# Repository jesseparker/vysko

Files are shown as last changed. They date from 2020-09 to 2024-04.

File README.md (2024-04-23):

# vysko
Promising results... (https://www.youtube.com/watch?v=EKHszj4jTb0) It's a video!  Click it!

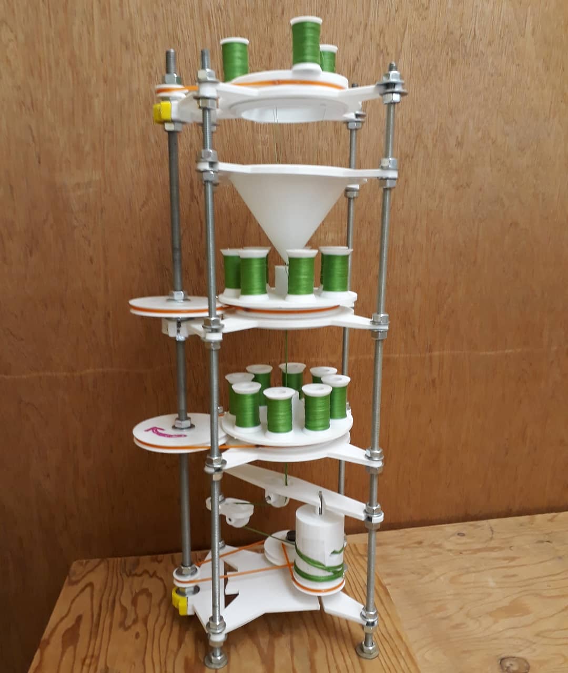
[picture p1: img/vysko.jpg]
Vysko Version 1


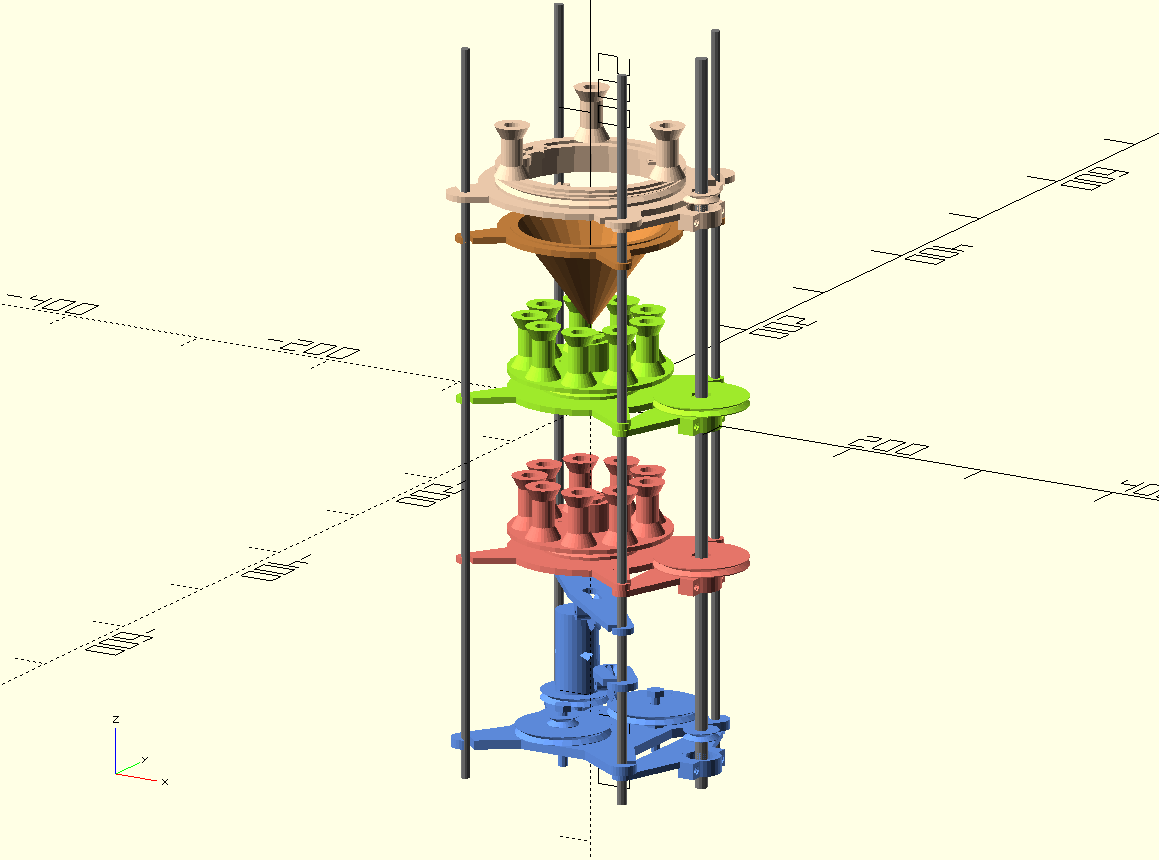
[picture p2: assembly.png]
OpenSCAD Model


Open Source Fuse Machines

2 machines are included here:

- A "visco" style fuse making machine
- A blackmatch making machine

VYSKO

Most of the files here are parts for a fuse weaving machine for making fuse with a powder core, wrapped in 2 layers of helical-wound thread.

If you search online you will find several handmade machines for making this kind of fuse.  They are typically 100% custom machines, and they are typically pretty big or even commercial-size.

This machine is designed for hobbyist use.  It is limited in the length of completed fuse that can be produced - there's only so much room for thread and finished fuse.  This machine is comparatively compact, is very adjustable, and can be made without specialized components.

In addition to several copies of several printed parts you will need:

- 4 1/4" threaded rod 24" long
- 1 5/16" threaded rod 24" long
- 2 2mm shaft 10 cm long
- 3 608 bearings ("skateboard bearings")
- 2 mm round polyurethane belt ~ 2 meters
- 2 1/4" 1 1/2" bolt
- 1 8" x 8" x 3/4" plywood baseplate
- 1000 yards cotton sewing thread
- Meal (pyrotechnic composition)
- ~ 130 1/4" nuts
- ~ 200 #12 flat washers
- ~ 20 5/16" nuts
- ~ 20 1/4" flat washers

Not much documentation available at this time!  Good luck!

Blackmatch Machine

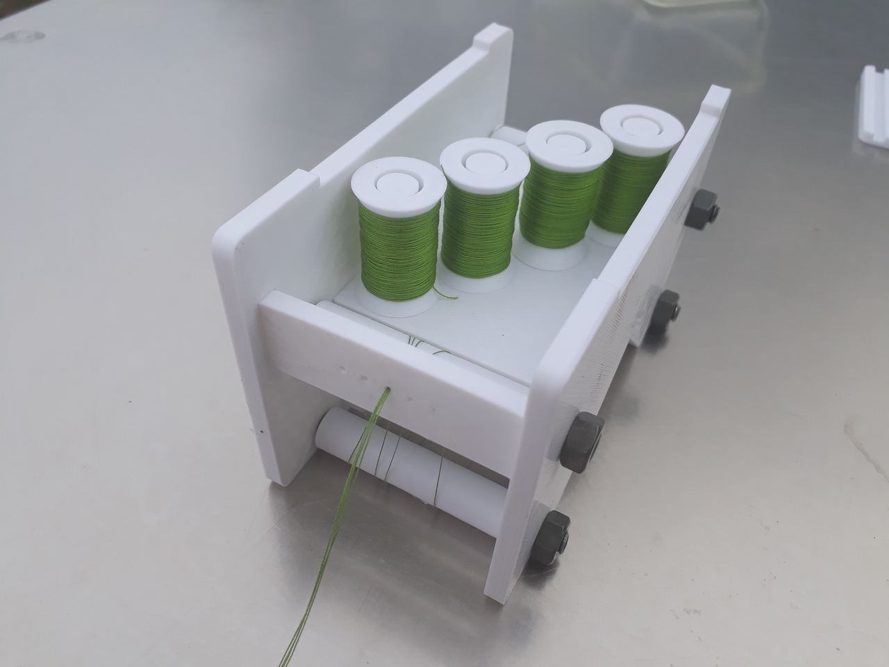
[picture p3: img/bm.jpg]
Blackmatch Version 1


This machine is for making blackmatch which is a basic fuse used in pyrotechnics.  Blackmatch can be used as a fuse, and is also used to make quickmatch.

In addition to about 12 printed parts you will need:

- 4 1/4" 3" bolts + nuts
- Cotton crochet thread #10 size (or similar)
- Meal + 5% dextrin (pyrotechnic composition)

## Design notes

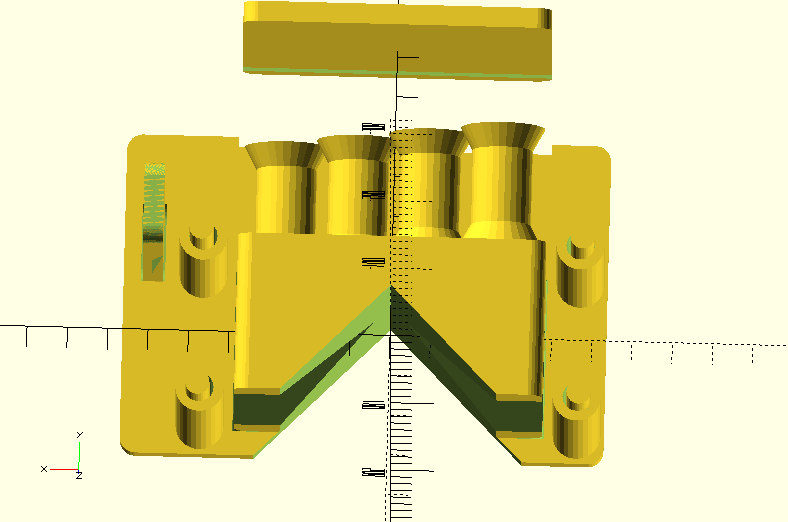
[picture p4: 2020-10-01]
img/bmatch6.png

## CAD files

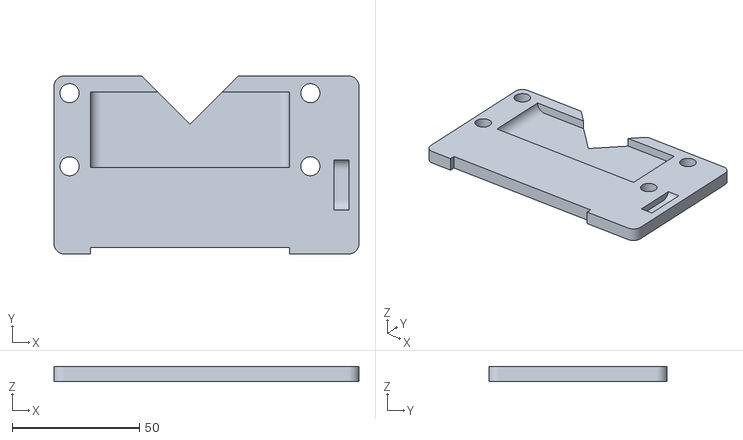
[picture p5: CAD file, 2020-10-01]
stl/blackmatch/side_b.stl
120.0 x 70.0 x 6.00

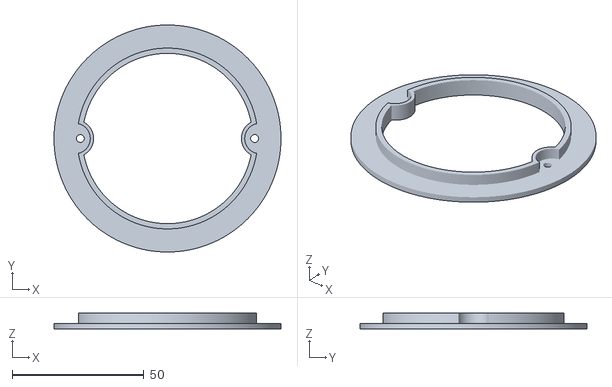
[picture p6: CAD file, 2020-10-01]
stl/vysko/spinner_key_x3.stl
86.0 x 86.0 x 6.00

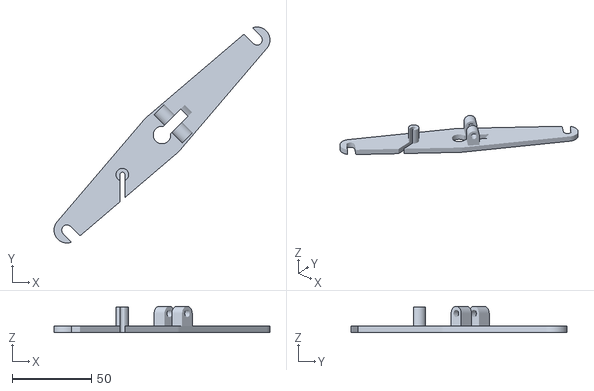
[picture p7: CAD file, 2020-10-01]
stl/vysko/strut_center_pulley.stl
136.2 x 136.2 x 16.6

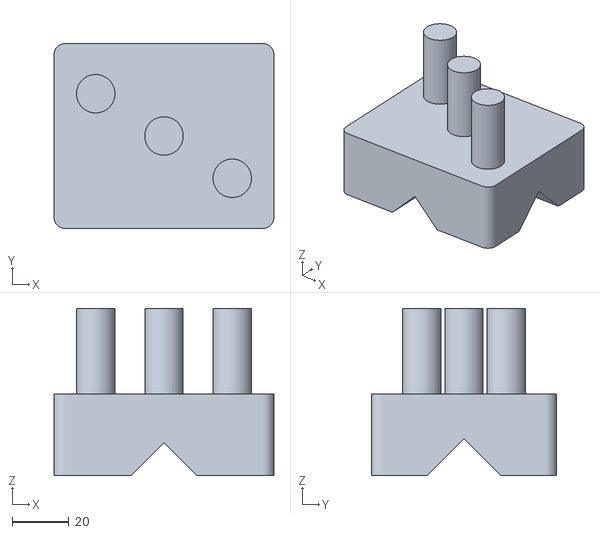
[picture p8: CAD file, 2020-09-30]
stl/blackmatch/body.stl
77.2 x 65.0 x 58.8

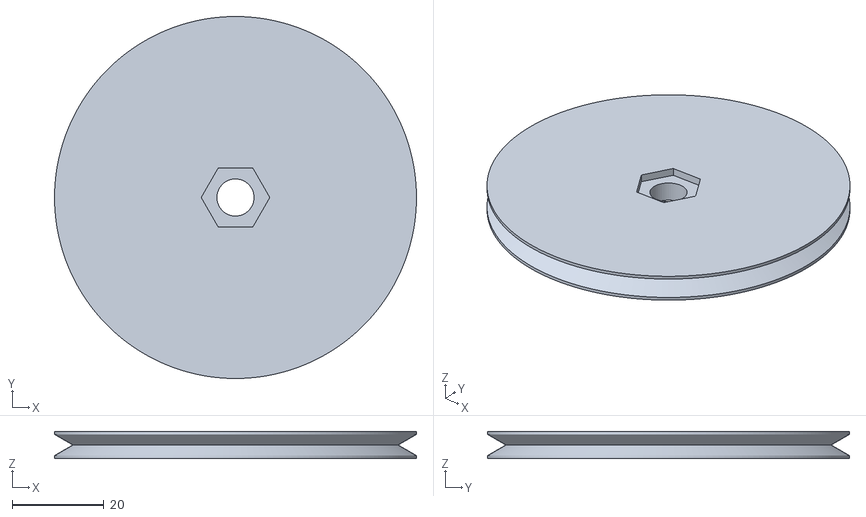
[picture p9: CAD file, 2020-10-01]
stl/vysko/driveshaft_pulley_75mm.stl
79.0 x 79.0 x 6.00

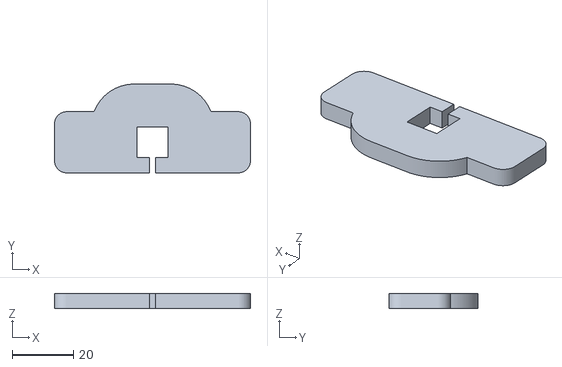
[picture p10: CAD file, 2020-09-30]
stl/blackmatch/die_holder.stl
64.0 x 29.0 x 5.00

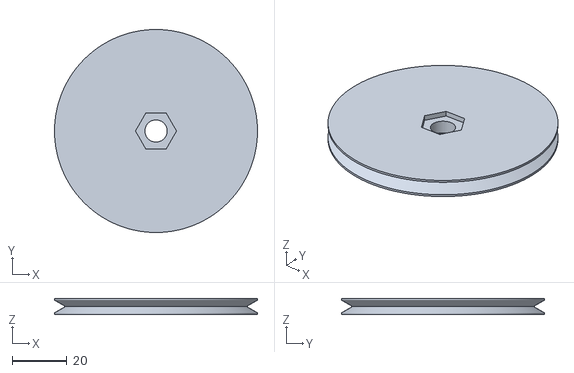
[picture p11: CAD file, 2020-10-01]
stl/vysko/driveshaft_pulley_70mm.stl
74.0 x 74.0 x 6.00

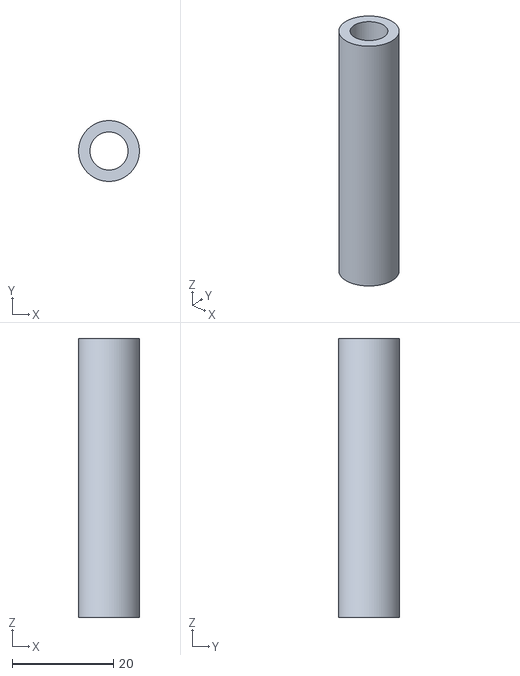
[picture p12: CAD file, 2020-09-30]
stl/blackmatch/roller_x4.stl
12.0 x 12.0 x 55.0

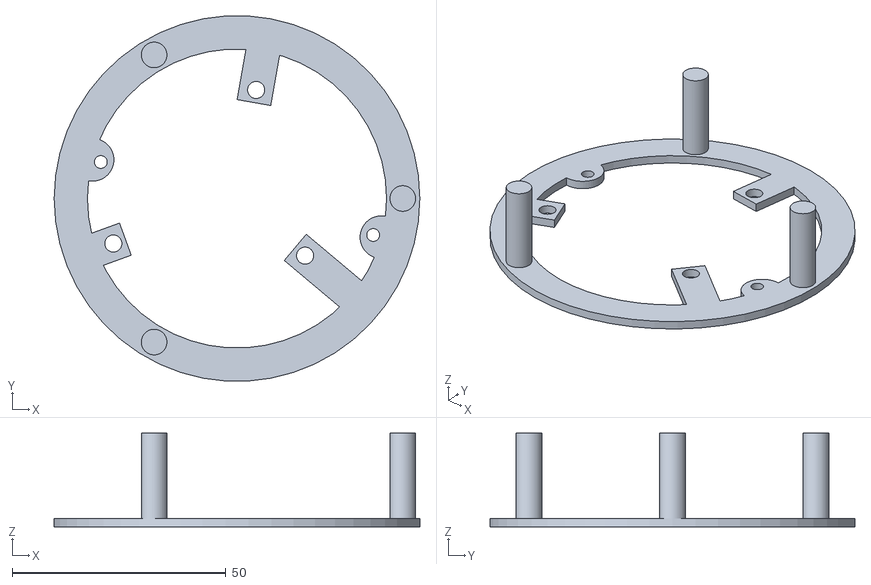
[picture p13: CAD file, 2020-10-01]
stl/vysko/tracer_plate.stl
85.6 x 85.4 x 22.0

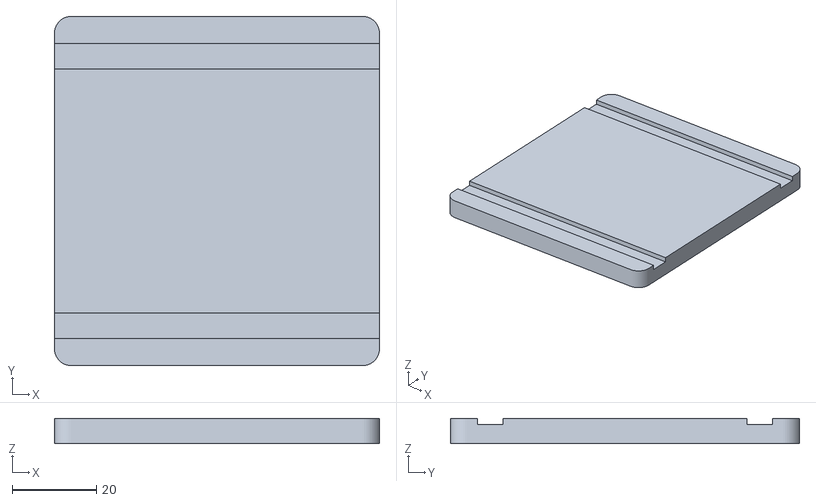
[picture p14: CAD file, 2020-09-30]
stl/blackmatch/retainer.stl
77.2 x 83.0 x 6.00

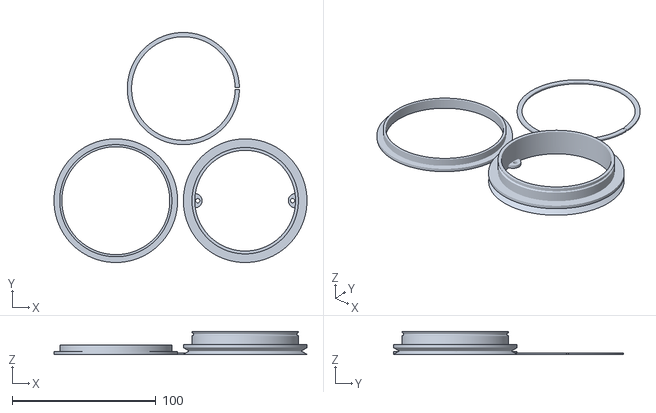
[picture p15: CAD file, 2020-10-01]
stl/vysko/spinner_bearing_x3.stl
176.0 x 160.0 x 16.1

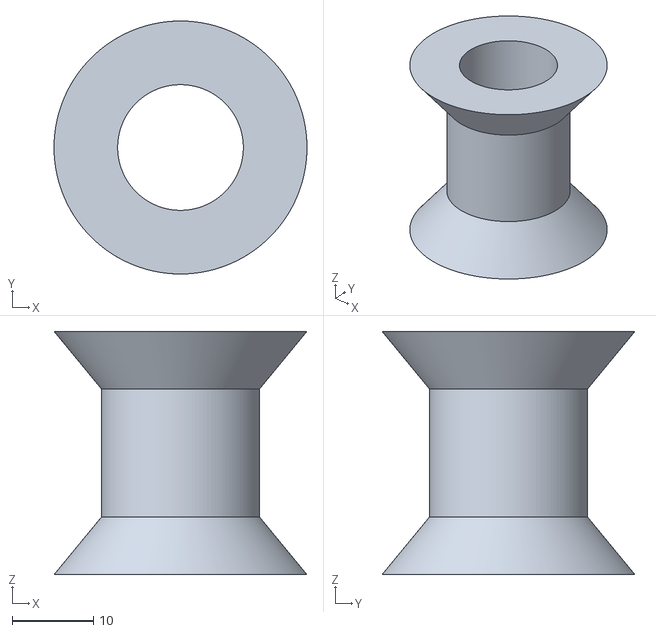
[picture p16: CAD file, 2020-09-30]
stl/blackmatch/spool_x3.stl
31.2 x 31.2 x 30.0

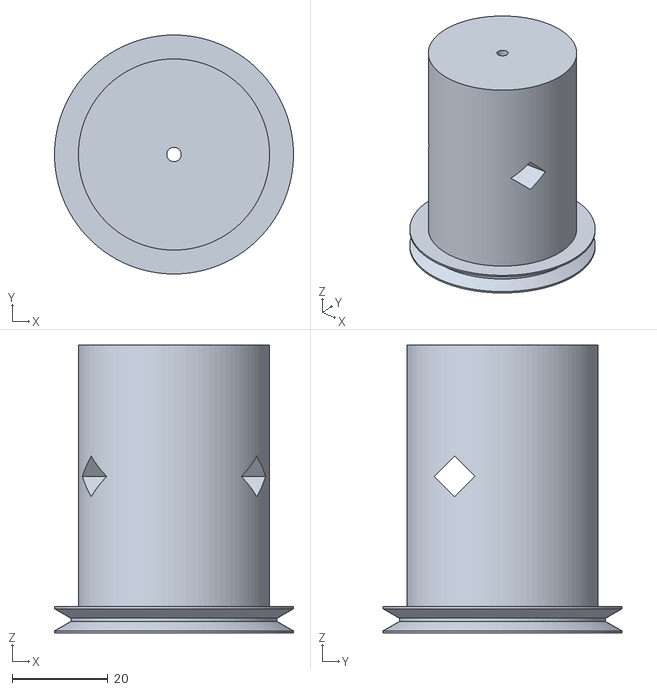
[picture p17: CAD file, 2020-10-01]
stl/vysko/drum.stl
50.0 x 50.0 x 60.2

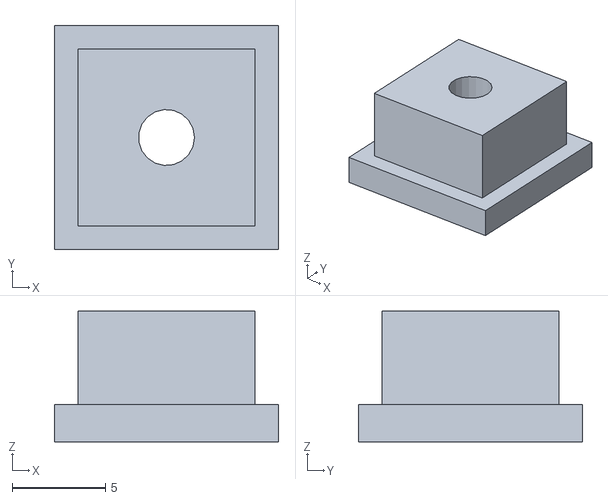
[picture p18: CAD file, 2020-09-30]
stl/blackmatch/die_3mm.stl
12.0 x 12.0 x 7.00

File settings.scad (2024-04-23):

//
//$fn = 100;
//$fn = 30;
smidge=.01;

lhf = .35;  // Layer Height FFFFirst
lh = .3; // Layer Height

// in this model there are "z axis" tolerances that are 
// in the range of a 3d printer layer height.  Some dimensions 
// need to be modelled as actual printed heights.  Adjust lhf and lh
// (above) for your slicer settings.
// layer_multiple() returns the closest layer height >= a distance
function layer_multiple(z) = (z <= lhf) ? lhf : lhf+lh*(ceil((z-lhf)/lh));
//foo = layer_multiple(100);
//echo(foo);

frame_x = 120;
frame_y = frame_x;
frame_rod_diameter=8;

frame_rod_r = 6.5/2;
frame_length = 500;


drive_axle_r = 8.1/2;
drive_axle_bearing_id = 8;
drive_axle_bearing_od = 22.5;
drive_axle_bearing_t = 8;

bearing_holder_wall = 1.2;
bearing_holder_tie_hole_r = 3/2;
bearing_holder_cut = -1;

bearing_pillow_rim_t = 2;
bearing_pillow_side_t = 1.5;
bearing_pillow_screw_thread_r = 3/2;
bearing_pillow_screw_shank_r = 4/2;
bearing_pillow_screw_head_r = 6/2;

drive_position_x = frame_x/2+ 25;
drive_position_y = 0;

strut_t = layer_multiple(4);

//spool
spool_d = 15;
spool_h = 35;
spool_flange_ratio=.8;
spool_hole = spool_d - 4; // hole diameter
spool_slope=1/6; // angle of conical section
spool_shaft_tol=2;

// rollers for winder 
center_pulley_r = 10;
center_pulley_t = 5;
center_pulley_angle = 45;
center_pulley_axle_r = 1.5;
center_pulley_axle_l = 30;

spinner_center_hole_r = 25;
tracer_center_hole_r = 55;

funnel_h = 70;
funnel_r = 50;
funnel_wall = 2.5;
funnel_flange = 3;
funnel_flange_t = 1;

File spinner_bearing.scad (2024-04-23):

include <settings.scad>
include <hollow_bearing.scad>
use <v_pulleys.scad>

$fa=1; $fs=.5;

inner_hole_r = spinner_center_hole_r;
shell_wall = 2;
inner_shell_wall = shell_wall;
outer_shell_wall = shell_wall/2;
shell_t = 2; 
flange_w = shell_t*2;
inner_outer_tolerance = 1;
journal_t = strut_t;
journal_tolerance = 1;
journal_tolerance_z = lh;

retainer_t = layer_multiple(1);
retainer_d = inner_shell_wall /2;
retainer_w = retainer_d*2+inner_outer_tolerance;
retainer_tolerance=.1;

spinner_pulley_t = 5;
spinner_single_pulley_t = 6;
spinner_pulley_attach = .1;

spinner_pulley_center_z = shell_t+journal_t/2+journal_tolerance_z/2+spinner_pulley_t/2-spinner_pulley_attach;
//spinner_pulley_center_z =0;
//spinner_pulley_center_z =0;
/*
shell_r = inner_hole_r + inner_shell_wall + outer_shell_wall + inner_outer_tolerance + flange_w ;
inner_shell_h = journal_t + shell_t*2 + retainer_t*2 + journal_tolerance_z+retainer_tolerance*2;
outer_shell_h = journal_t + shell_t +journal_tolerance_z;

*/

spinner_key_t = 2;
spinner_key_insert = 4;

module spinner_connect_holes() {
         translate([-inner_hole_r+2,0,-spinner_pulley_t+spinner_pulley_attach])
            cylinder(r=1.5,h=20,center=true);
         translate([inner_hole_r-2,0,-spinner_pulley_t+spinner_pulley_attach])
            cylinder(r=1.5,h=20,center=true);
}

module spinner_connect_tabs() {
    difference() {
        union() {
            translate([inner_hole_r,0,-spinner_pulley_t+spinner_pulley_attach])
                cylinder(r=5,h=2);
            translate([-inner_hole_r,0,-spinner_pulley_t+spinner_pulley_attach])
                cylinder(r=5,h=2);
        }
        spinner_connect_holes();
    }    
}
//spinner_connect_tabs();
module spinner_key(t=spinner_key_t, tol=0) {
    difference() {
        union() {
    difference() {
        union() {
        translate([0,0,-t/2])
            cylinder(r=shell_r, h=t, center=true);
            
        translate([0,0,spinner_key_insert/2])
            cylinder(r=inner_hole_r-tol/2, h=spinner_key_insert, center=true);
            
        translate([0,0,spinner_key_insert/2-smidge])
            cylinder(r=inner_hole_r-tol/2, h=spinner_key_insert, center=true);


            
        }
cylinder(r=inner_hole_r-tol/2-t, h=20, center=true);    
    }
    intersection() {
            translate([inner_hole_r,0,+(spinner_key_insert-t)/2])
                cylinder(r=5+t,h=t+spinner_key_insert, center=true);
            cylinder(r=inner_hole_r-tol/2, h=spinner_key_insert*2, center=true);
    }
    intersection() {
            translate([-inner_hole_r,0,+(spinner_key_insert-t)/2])
                cylinder(r=5+t,h=t+spinner_key_insert, center=true);
            cylinder(r=inner_hole_r-tol/2, h=spinner_key_insert*2, center=true);
    }
}
    translate([inner_hole_r,0,+(spinner_key_insert-t)/2+t])
        cylinder(r=5+tol/2,h=t+spinner_key_insert, center=true);
    translate([-inner_hole_r,0,+(spinner_key_insert-t)/2+t])
        cylinder(r=5+tol/2,h=t+spinner_key_insert, center=true);
         spinner_connect_holes();   
    }
}
//translate([0,0,-shell_t-journal_t/2-journal_tolerance_z/2-spinner_pulley_t/2-spinner_pulley_t+spinner_pulley_attach])
//!spinner_key();

module spinner_inner_shell() {

    inner_shell();
    translate([0,0,-spinner_pulley_t/2+spinner_pulley_attach])
    belt_pulley(
        d = shell_r*2-4,
        shaft_d=inner_hole_r*2,
        belt_d=2,
        t= spinner_pulley_t,
        wedge_factor=.4
    );
    spinner_connect_tabs();
}

//spinner_inner_shell();

module spinner_outer_shell() {
    outer_shell();
}

module spinner_journal() {
    journal();

}

module spinner_retainer_ring() {
    retainer_ring();
}

//module spinner_center_hole() {
//    center_hole();
//}

module spinner_bearing_assembly() {
//intersection() {
translate([0,0,shell_t+journal_t/2+journal_tolerance_z/2])
spinner_outer_shell();

    translate([0,0,-shell_t-journal_t/2-journal_tolerance_z/2]) {
    spinner_inner_shell();

   translate_retainer()
  spinner_retainer_ring();
}

translate([0,0,-shell_t-journal_t/2-journal_tolerance_z/2-spinner_pulley_t+spinner_pulley_attach-1])
spinner_key(tol=1.5);
    

spinner_journal();
//}

}
//spinner_center_hole();
spinner_bearing_assembly();

module spinner_bearing_print_all() {
translate([0,0,0])
rotate(180, [0,1,0])
spinner_outer_shell();
translate([shell_r*2+4,0,spinner_pulley_t-spinner_pulley_attach]) 
    spinner_inner_shell();
    
//translate([0,shell_r*2+flange_w*2,journal_t/2])
//spinner_journal();
//translate([shell_r+flange_w*3+inner_hole_r,shell_r+flange_w*2+inner_hole_r,retainer_t/2])
translate([shell_r+flange_w,shell_r+inner_hole_r,retainer_t/2])
spinner_retainer_ring();
    
}


//spinner_bearing_print_all();

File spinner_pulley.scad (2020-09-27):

include <jplib.scad>
include <settings.scad>
include <spinner_bearing.scad>
//include <bearing.scad>
include <nuts_washers.scad>
include <v_pulleys.scad>
//include <rods.scad>

//$fn = 30;

module spinner_single_pulley(d=20) {
    difference() {
        union() {
            belt_pulley(
                d = d,
                shaft_d=drive_axle_r*2,
                belt_width=3,
                slope=.5,
                t= spinner_single_pulley_t
            );
        }
        translate([0,0,-spinner_pulley_center_z])
            bearing_translate()
                drive_bearing_top_washer_translate()
                    drive_bearing_top_nut_translate()
                        nut_5_16();
    }
}
module spinner_double_pulley() {
    difference() {
        union() {
            belt_pulley(
                d = 20,
                shaft_d=drive_axle_r*2,
                belt_width=3,
                slope=.5,
                t= spinner_pulley_t
            );
            translate([0,0,spinner_pulley_t-.05])
            belt_pulley(
                d = 20,
                shaft_d=drive_axle_r*2,
                belt_width=3,
                slope=.5,
                t= spinner_pulley_t
            );
        }
        translate([0,0,-spinner_pulley_center_z])
            bearing_translate()
                drive_bearing_top_washer_translate()
                    drive_bearing_top_nut_translate()
                        nut_5_16();
    }
}

//rotate(180, [0,1,0]) spinner_double_pulley();

module drive_translate() {
    translate([0,drive_position_x,0]) children();
}

module bearing_translate() {
    z = - drive_axle_bearing_t/2
        - bearing_pillow_side_t
        + journal_t/2
        +.3;
    translate([0,0,z]) children();
}

module drive_bearing_top_washer_translate() {
    //z = drive_axle_bearing_t/2;
    z = 0;  
    translate([0,0,z]) children();
}

module drive_bearing_top_nut_translate() {
    z = washer_5_16_t;
    //z=0;
    translate([0,0,z]) children();
}

rotate(180,[0,1,0])
spinner_bearing_assembly();
if (false) {
    
drive_translate()
    bearing_translate()
        bearing_holder_top();

//drive_translate()
    //translate([0,0,-3.5])
    //bearing_holder_bottom();

drive_translate()
    bearing_translate()
        bearing();



//drive_translate()
//    bearing_translate()
//        drive_bearing_top_washer_translate()
//            washer_5_16();

drive_translate()
    bearing_translate()
        drive_bearing_top_washer_translate()
            drive_bearing_top_nut_translate()
                nut_5_16();


}

drive_translate()
//     bearing_translate()
///        drive_bearing_top_washer_translate()
 //           drive_bearing_top_nut_translate()
   translate([0,0,spinner_pulley_center_z])
        //spinner_double_pulley();
        rotate(180,[1,0,0])
        spinner_single_pulley(d=75);
        
        
//!rotate(180,[1,0,0]) spinner_single_pulley(d=20);

module to_print() {
//        rotate(180,[1,0,0])
 //       spinner_single_pulley(d=70);    
    
 //       rotate(180,[1,0,0])
 //       spinner_single_pulley(d=75);
    
        rotate(180,[1,0,0])
        spinner_single_pulley(d=20);   
    }

//!to_print();

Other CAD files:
stl/blackmatch/side_a.stl
stl/vysko/bearing_pillow_top_x3.stl
stl/vysko/funnel.stl
stl/vysko/spinning_plate_cw.stl
spinning_plate.scad
assembly.scad
bearing.scad
blackmatch.scad
driveshaft_pulley.scad
funnel.scad
hollow_bearing.scad
jplib.scad
motor.scad
nuts_washers.scad
rb-pulleys.scad
rods.scad
roller.scad
spool.scad
stl/vysko/driveshaft_pulley_20mm_x2.stl
stl/vysko/funnel_strut.stl
stl/vysko/reducer.stl
stl/vysko/roller_x2.stl
stl/vysko/spinning_plate_ccw.stl
stl/vysko/spool_x19.stl
stl/vysko/strut_c.stl
stl/vysko/strut_drum.stl
stl/vysko/strut_r45_x3.stl
stl/vysko/strut_roller_c.stl
stl/vysko/strut_side_x3.stl
strut.scad
strut_spinner.scad
strut_tracer.scad
sub_funnel.scad
sub_sidestrut.scad
sub_spinner.scad
sub_tracer.scad
sub_winder.scad
tracer_bearing.scad
tracer_plate.scad
trapezoid_groove.scad
v_groove.scad
v_pulleys.scad
whole.scad
winder.scad

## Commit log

2018-01-04 Model for drive pulley with accurate z position
    [bearing.scad, drive-alignment-mockup.scad, nuts_washers.scad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]
2018-02-24 stronger strut with outboard drive
    [bearing.scad, rods.scad, strut.scad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]
2019-11-18 Unknown quantity of stale tweaks
    [bearing.scad, nuts_washers.scad, rods.scad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]
2019-11-19 most parts rev 1
    [funnel.scad, spinning_plate.scad, tracer_bearing.scad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]
2019-11-21 gear library
2019-11-21 mo work
    [funnel.scad, puller.scad]
2019-11-22 2nd concept stepped gear train
    [puller.scad]
2020-08-29 Black match machine
    [blackmatch.scad, jplib.scad, settings.scad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]
2020-09-09 start of basic take-up stage
    [rb-pulleys.scad, rods.scad, roller.scad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]
2020-09-10 switch to 3 larger spools. easier access to thread die
    [blackmatch.scad]
2020-09-11 complete take-up stage
    [bearing.scad, nuts_washers.scad, rods.scad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]
2020-09-19 Switching to round belts and v-pulleys
    [bearing.scad, driveshaft_pulley.scad, rods.scad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]
2020-09-25 switch to separate drive axle, etc
    [blackmatch.scad, settings.scad, spinner_bearing.scad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]
2020-09-27 2-piece funnel, higher ratio pulleys for spinners
    [driveshaft_pulley.scad, funnel.scad, settings.scad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]
2020-09-30 Removing old files that would confuse people
    [assembly.scad, puller.scad, sidebar.scad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]
2020-09-30 stls for blackmatch machine
    [blackmatch.scad, body.stl, die_3mm.stl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]
2020-10-01 stls for vysko
    [bearing_pillow_top_x3.stl, driveshaft_pulley_20mm_x2.stl, driveshaft_pulley_70mm.stl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]
2020-10-01 no gears used - belts!
2020-10-03 wider tracer, modular spinner, triple drum reduction
    [driveshaft_pulley.scad, settings.scad, spinner_bearing.scad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]
2020-10-03 more tracer mods
    [strut_tracer.scad, tracer.scad]
2020-10-10 Add drive motor base. More improvements for v2. dual reduction for winder. Modular die for spinning stages
    [motor.scad, spinning_plate.scad, tracer_bearing.scad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]
2020-10-12 More reduction for drum - was 1:15 now 1:30
    [winder.scad]
2020-10-12 Adjust drum ratio again. Now 42:1
    [winder.scad]
2024-03-29 putting the whole mechanism into 1 file
    [driveshaft_pulley.scad, funnel.scad, roller.scad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]
2024-03-30 avoid copypasta for side strut
    [sub_funnel.scad, sub_spinner.scad, sub_tracer.scad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]
2024-03-30 better filename
    [assembly.scad]
2024-03-31 fix tracer bearing
    [assembly.scad, sub_tracer.scad, tracer_bearing.scad]
2024-04-23 more spools with higher gear ration. better overall assembly
    [settings.scad, spinner_bearing.scad, spinning_plate.scad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]
2024-04-23 add picture
    [sub_spinner.scad]
